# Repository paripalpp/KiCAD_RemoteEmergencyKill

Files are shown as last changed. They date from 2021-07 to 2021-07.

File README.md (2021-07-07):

# 遠隔緊急緊急停止スイッチ

 遠隔緊急停止スイッチ用基板。子機と親機で共通の基盤を使用。

## KiCADファイル

 KiCADファイルを開くときは[KiCAD_libralies](https://github.com/paripalpp/KiCAD_libralies)を追加して下さい。

## 使用部品

- interplan im920s
  - 920MHz帯の無線ユニットで接点入出力モード(注:ファームウェア1.16以降)をつかってスタンドアロンで動作させる。
  - [製品ページ](https://www.interplan.co.jp/solution/wireless/im920s/)
- JST XAコネクタ
  - 2.54mmピッチの圧着コネクタでサイド型を信号出力、電源に使用
  - [製品ページ](https://www.jst-mfg.com/product/detail.php?series=272)
- IS-1245T-G
  - Switronicの基板用スライドスイッチ、電源スイッチに使用
  - [datasheet](https://akizukidenshi.com/download/ds/switronic/IS-1245T-G.PDF)
- LP401730
  - 1sell LiPoバッテリー 150mA
  - [datasheet](https://www.eemb.com/public/Download/Rechargeable-Lithium-Battery/Li-Polymer-Battery/Standard-Version/LP401730.pdf)
- MCP73831-2ATI/OT
  - 単セルLiPoバッテリー充電コントローラicで子機のLiPoバッテリーを充電する
  - [datasheet](https://akizukidenshi.com/download/ds/microchip/mcp73831_73832.pdf)
- RBS1MM40ATR
  - 超低Vfショットキーバリアダイオード、電源供給を5V(外部)とLiPoバッテリー(内蔵)で切り替える
  - [製品ページ](https://www.rohm.co.jp/products/diodes/schottky-barrier-diodes/ultra-low-vf/rb161mm-20-product)
- ADP151AUJZ-3.3
  - 低雑音、低損失リニアレギュレータ、im920への電源供給用
  - [datasheet](https://akizukidenshi.com/download/ds/analog/ADP151_jp.pdf)

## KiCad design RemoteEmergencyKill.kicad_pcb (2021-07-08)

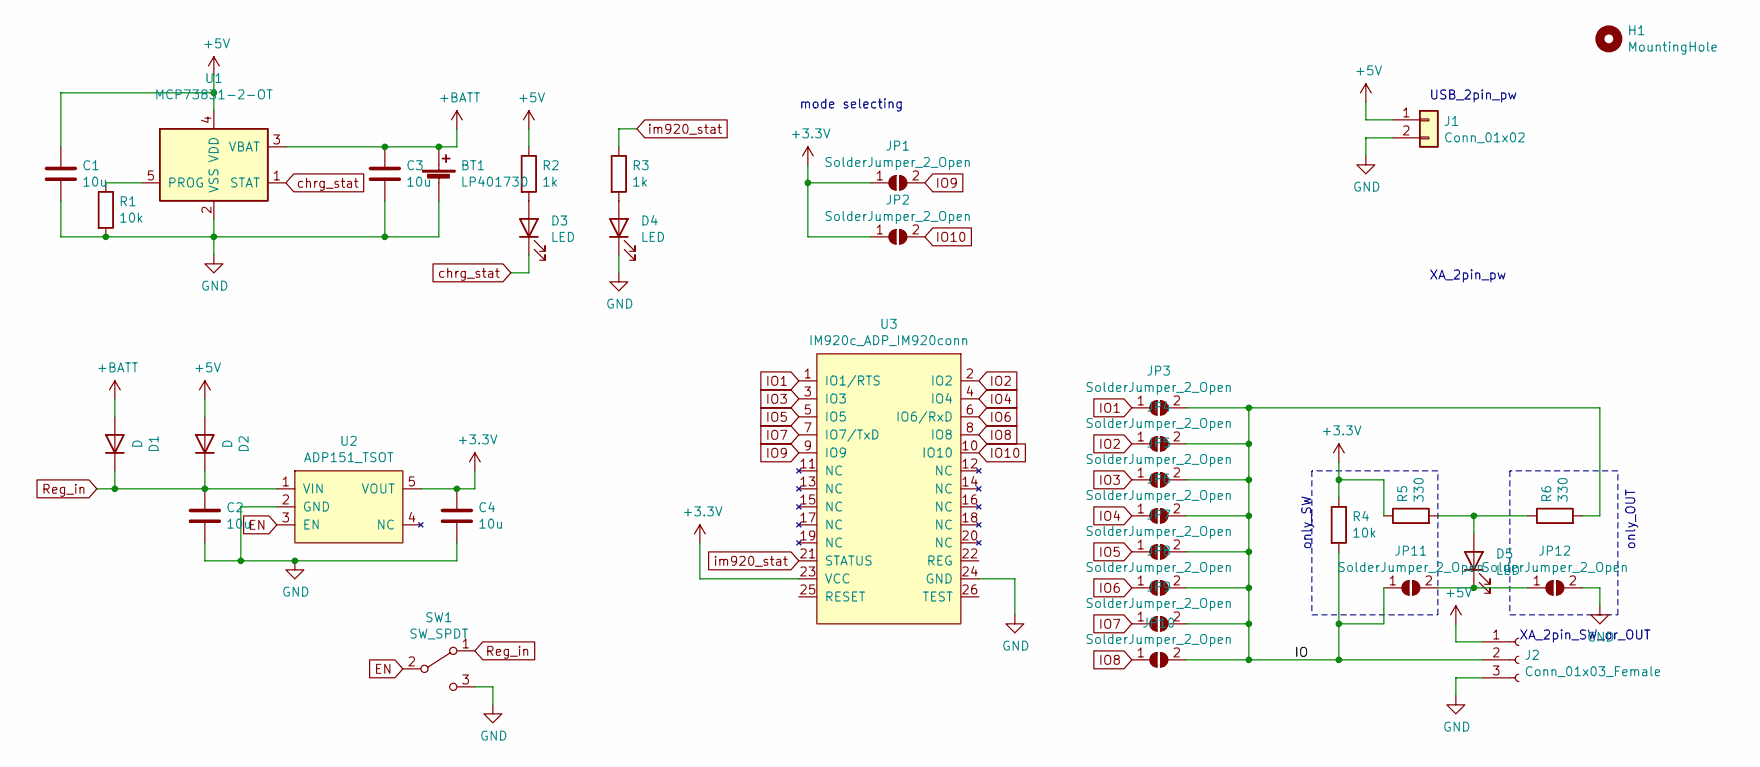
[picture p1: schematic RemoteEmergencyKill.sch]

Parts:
BT1: LP401730
C1, C2, C3, C4: 10u; C_0805_2012Metric
D1, D2: D; D_SOD-123F
D3, D4, D5: LED; LED_0603_1608Metric
H1: MountingHole; MountingHole_2.2mm_M2_Pad_Via
J1: Conn_01x02; USB micro B 2pin
J2: Conn_01x03_Female; S03B-XASK-1
JP1, JP2, JP3, JP4, JP5, JP6, JP7, JP8, JP9, JP10, JP11, JP12: SolderJumper_2_Open; SolderJumper-2_P1.3mm_Open_TrianglePad1.0x1.5mm
R1, R4: 10k; R_0603_1608Metric
R2, R3: 1k; R_0603_1608Metric
R5, R6: 330; R_0603_1608Metric
SW1: SW_SPDT; IS-1245T-G
U1: MCP73831-2-OT; SOT-23-5
U2: ADP151_TSOT; TSOT-23-5
U3: IM920c_ADP_IM920conn; IM920(IM920c_ADP)

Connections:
+3V3: C4.1, JP1.1 (A), JP2.1 (A), R4.1, R5.1, U2.5 (VOUT), U3.23 (VCC)
+5V: C1.1, D2.2 (A), J1.1, J2.1, R2.1, U1.4 (VDD)
+BATT: BT1.1 (+), C3.1, D1.2 (A), U1.3 (VBAT)
/IO: J2.2, JP3.2 (B), JP4.2 (B), JP5.2 (B), JP6.2 (B), JP7.2 (B), JP8.2 (B), JP9.2 (B), JP10.2 (B), JP11.1 (A), R4.2, R6.2
EN: SW1.2 (B), U2.3 (EN)
GND: BT1.2 (-), C1.2, C2.2, C3.2, C4.2, D4.1 (K), J1.2, J2.3, JP12.2 (B), R1.2, SW1.3 (C), U1.2 (VSS), U2.2 (GND), U3.24 (GND)
IO1: JP3.1 (A), U3.1 (IO1/RTS)
IO2: JP4.1 (A), U3.2 (IO2)
IO3: JP5.1 (A), U3.3 (IO3)
IO4: JP6.1 (A), U3.4 (IO4)
IO5: JP7.1 (A), U3.5 (IO5)
IO6: JP8.1 (A), U3.6 (IO6/RxD)
IO7: JP9.1 (A), U3.7 (IO7/TxD)
IO8: JP10.1 (A), U3.8 (IO8)
IO9: JP1.2 (B), U3.9 (IO9)
IO10: JP2.2 (B), U3.10 (IO10)
unnamed: D3.2 (A), R2.2
unnamed: D4.2 (A), R3.2
unnamed: D5.1 (K), JP11.2 (B), JP12.1 (A)
unnamed: D5.2 (A), R5.2, R6.1
unnamed: R1.1, U1.5 (PROG)
Reg_in: C2.1, D1.1 (K), D2.1 (K), SW1.1 (A), U2.1 (VIN)
chrg_stat: D3.1 (K), U1.1 (STAT)
im920_stat: R3.1, U3.21 (STATUS)

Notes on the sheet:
mode selecting
USB_2pin_pw
XA_2pin_pw
only_SW
XA_2pin_SW_or_OUT
only_OUT

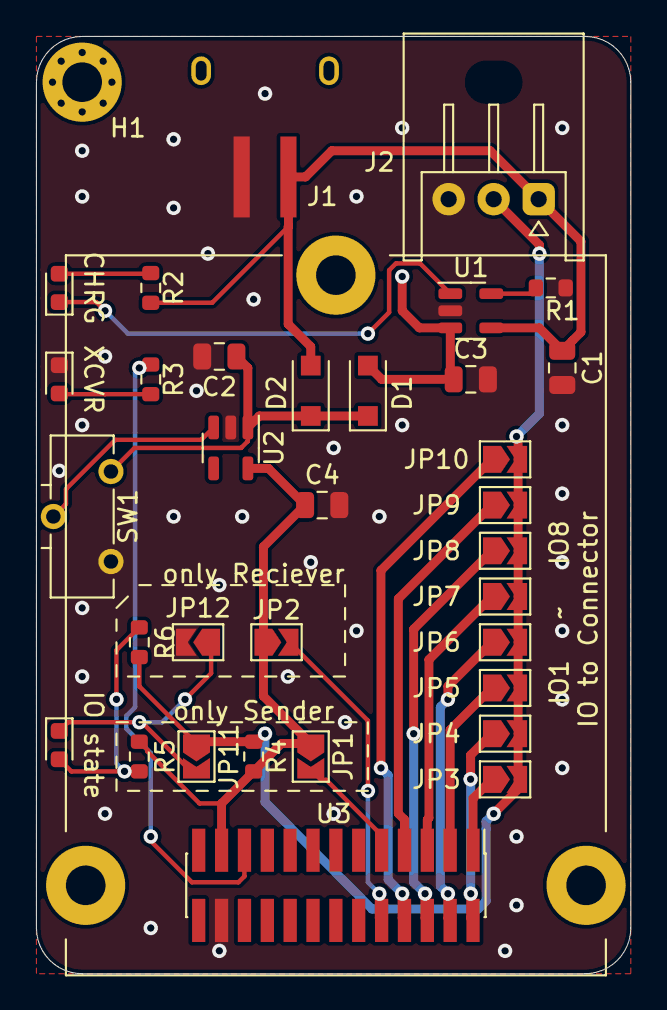
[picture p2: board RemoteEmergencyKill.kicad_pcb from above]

Board: 2 copper layers, 33.0 x 52.1 mm, 35 parts (1 on the bottom side), 24 nets.

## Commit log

2021-07-04 schematic update
    [RemoteEmergencyKill.sch]
2021-07-05 changed regulator
    [RemoteEmergencyKill.sch]
2021-07-07 pcb file added
    [RemoteEmergencyKill.kicad_pcb, RemoteEmergencyKill.sch]
2021-07-08 proted gbr files
    [RemoteEmergencyKill-B_Cu.gbr, RemoteEmergencyKill-B_Mask.gbr, RemoteEmergencyKill-B_Paste.gbr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]
